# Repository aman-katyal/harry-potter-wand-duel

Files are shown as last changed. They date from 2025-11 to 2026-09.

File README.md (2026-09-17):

# Harry Potter Wand Duel - Embedded Edge-AI System

An interactive, dual-wand dueling system built on the Raspberry Pi RP2040 microcontroller. The wand tracks physical spell-casting gestures in real time using on-device machine learning (TinyML), transmits spell data wirelessly over 38 kHz modulated infrared, renders real-time combat status and animations on a 16x16 RGB LED matrix, and delivers tactile feedback via an onboard haptic motor driver.

Designed and developed for **ECE 362: Microprocessor Systems and Interfacing** at Purdue University.

---

## System Architecture

```
                      +-------------------------------------------------------+
                      |                 Raspberry Pi RP2040                   |
                      |                                                       |
                      |  +-------------------------------------------------+  |
                      |  | Core 0: Real-Time Engine & Peripherals          |  |
                      |  |                                                 |  |
                      |  |  * 74 Hz IMU Poller (BNO085 over I2C0)          |  |
                      |  |  * 3-Second 6-Axis Ring Buffer                  |  |
                      |  |  * WS2812 16x16 Matrix Controller (PIO + DMA)   |  |
                      |  |  * 38 kHz NEC IR Transmitter (PIO State Machine)|  |
                      |  |  * NEC Demodulating IR Receiver (PIO Interrupt) |  |
                      |  |  * DRV2605 Haptic Feedback (I2C0)               |  |
                      |  |  * Game State Machine, Health Bar & Shield Logic|  |
                      |  +-----------------------+-------------------------+  |
                      |                          |                             |
                      |                  Multicore Hardware                    |
                      |                    FIFO + Mutex                        |
                      |                          |                             |
                      |  +-----------------------v-------------------------+  |
                      |  | Core 1: TinyML Inference Engine                 |  |
                      |  |                                                 |  |
                      |  |  * Edge Impulse TFLite Micro Runtime            |  |
                      |  |  * 1650 ms Sliding Window Feature Extractor     |  |
                      |  |  * CMSIS-DSP Accelerated Neural Classifier      |  |
                      |  |  * K-Means Anomaly Detection Engine             |  |
                      |  +-------------------------------------------------+  |
                      +-------------------------------------------------------+
```

---

## Hardware Specifications

| Component | Part / IC | Interface | Description |
|---|---|---|---|
| **Microcontroller** | SparkFun Pro Micro RP2040 | Dual ARM Cortex-M0+ @ 133 MHz | Primary compute module with 264 KB SRAM and 2 MB Flash. |
| **Inertial Measurement** | Adafruit BNO085 | I2C0 (Fast Mode, 400 kHz) | 9-DOF IMU with onboard ARM Cortex-M0+ running Hillcrest SH-2 sensor fusion (Linear Accel + Rotation Vector). |
| **Haptics** | TI DRV2605L | I2C0 (Shared bus) | ERM/LRA haptic driver providing distinct wave sensations for spell casts, hits, and shield deployment. |
| **Display Matrix** | 16x16 WS2812B (256 LEDs) | PIO0 (Custom State Machine) | High-speed serialized 800 kHz pixel protocol driven directly by RP2040 PIO with no CPU bit-banging. |
| **IR Transmitter** | 940 nm High-Output IR LED | PIO1 (38 kHz Carrier Generator) | Hardware-timed NEC protocol encoding with 38 kHz carrier frequency modulation. |
| **IR Receiver** | TSOP38238 (38 kHz Demodulator) | PIO / Edge-triggered ISR | Demodulates incoming player commands and validates opponent player IDs. |
| **Shield Trigger** | Tactile Switch | GPIO 21 (Active High) | Hardware input to raise the defensive barrier and trigger hit immunity. |
| **Custom PCB** | 2-Layer KiCad Design | Multi-rail Power (5V / 3.3V) | Custom wand PCB integrating MCU, sensor breakouts, power regulation, and FET driver circuits. |

---

## Key Technical Challenges & Engineering Solutions

### 1. Dual-Core Real-Time Decoupling
Running TinyML neural network inference on continuous 6-axis sensor streams requires 60–90 ms of sustained computation per window. If executed synchronously on a single core:
- Sensor polling intervals would jitter, corrupting frequency-domain feature extraction.
- Incoming 38 kHz IR pulses would be dropped, causing missed hits during combat.
- LED matrix refresh routines would stall, resulting in visible visual stutter.

**Solution:** The system splits tasks across both RP2040 cores:
- **Core 0** handles strictly deterministic real-time tasks: reading the BNO085 at exactly 74 Hz, pushing samples to a circular buffer, rendering animations, managing IR transceiver state machines, and evaluating the duel state machine.
- **Core 1** operates as a co-processor dedicated solely to TinyML execution. When Core 0 detects an active gesture, it copies a 1650 ms sliding window (732 float features) into an exchange buffer and signals Core 1. Core 1 runs inference and returns a packed 32-bit result (`spell_id`, `confidence`, `anomaly_score`) via the RP2040 hardware FIFO.

### 2. False-Positive Filtering ("Leaky Bucket" Accumulator)
Natural wand handling and rapid arm movements can produce transient sensor spikes that momentarily fool an ML classifier.
- Instead of firing immediately on a single inference hit, the firmware uses an integrating leaky-bucket filter (`SPELL_TRIGGER_TARGET = 7`, `SPELL_DECAY_RATE = 2`).
- A spell is only cast when consecutive inferences consistently recognize the same gesture above the confidence threshold (`>= 0.90`).
- Individual spells use dynamic anomaly ceilings (e.g., `2.3` for Aguamenti vs. `2.6` for Stupefy) to cleanly reject out-of-distribution movements.

### 3. Hardware Peripheral Offloading via PIO
- **WS2812B Protocol:** Rather than tying up the CPU with tight assembly loops for the strict 800 kHz NZR timing, a custom PIO program streams pixel color buffers directly to the matrix.
- **38 kHz IR Modulation:** The 38 kHz carrier square wave and NEC pulse-distance bit-timing are generated in hardware using a PIO state machine, ensuring precise modulation independent of CPU load.

---

## Combat & Game Mechanics

- **Spells:**
  - **Aguamenti (Water Spell):** Forward-sweeping motion -> triggers blue matrix firework animation, distinct haptic vibration, and broadcasts NEC command `10` over IR. Deals 2 damage.
  - **Stupefy (Stun Spell):** Sharp diagonal slash -> triggers red matrix firework animation, heavy haptic jolt, and broadcasts NEC command `20` over IR. Deals 2 damage.
- **Protego (Shield):** Pressing the shield button deploys an animated protective blue barrier on the matrix for 1.5 seconds. During this window, any incoming IR hits are flushed from the queue and ignored (temporary immunity). A 10-second cooldown timer is enforced before the shield can be redeployed.
- **Health System:** A perimeter health bar tracks player health (initialized to 10 HP). When health drops to 0, an animated defeat screen is displayed and casting is locked out until respawn.
- **Multiplayer Duel Configuration:**
  - In [`firmware/src/sys_config.h`](firmware/src/sys_config.h), set `PLAYER_ID` to `1` or `2` to assign wand identity.
  - Set `ALLOW_SELF_HIT` to `1` for single-wand solo testing, or `0` for two-player competitive duels (to prevent bouncing off walls and self-inflicting damage).

---

## Hardware Pinout Map

| RP2040 GPIO | Function | Peripheral |
|---|---|---|
| **GPIO 4** | I2C0 SDA | BNO085 IMU & DRV2605 Haptic Driver |
| **GPIO 5** | I2C0 SCL | BNO085 IMU & DRV2605 Haptic Driver |
| **GPIO 6** | Input / PIO | TSOP38238 38 kHz IR Receiver |
| **GPIO 16** | Output / PIO | IR LED Driver (38 kHz modulated output) |
| **GPIO 20** | Output / PIO | WS2812B 16x16 LED Matrix Data Line |
| **GPIO 21** | Input (Pull-Down) | Shield Tactile Switch |

---

## Repository Structure

```
.
├── firmware/                   # Primary dual-core wand firmware (PlatformIO project)
│   ├── src/                    # Application source files
│   │   ├── main.c              # Core 0 loop, hardware init, duel logic, IR/LED handling
│   │   ├── sys_config.h        # Pin assignments, tuning thresholds, player identity
│   │   ├── ei_bridge.cpp       # Edge Impulse C++ wrapper for Core 1 inference
│   │   └── ei_bridge.h
│   ├── lib/                    # Device drivers and neural network model
│   │   ├── Adafruit_BNO08x/    # Hillcrest SH-2 IMU driver
│   │   ├── haptics/            # DRV2605 haptic motor driver
│   │   ├── ir_receiver/        # NEC IR decoder implementation
│   │   ├── ir_transmitter/     # NEC IR encoder & emitter
│   │   ├── led_matrix/         # Matrix animations (fireworks, shield, healthbar)
│   │   └── edge-impulse-model/ # Exported TinyML model with CMSIS-DSP kernels
│   ├── pio/                    # PIO assembly files (WS2812 timing, IR carrier)
│   └── platformio.ini          # Build configuration (Pico-SDK, multicore, CMSIS flags)
│
├── hardware/                   # KiCad electrical design & PCB layout
│   ├── ece362project.kicad_sch # Top-level schematic
│   ├── ece362project.kicad_pcb # 2-layer routed PCB layout
│   ├── *.kicad_sch             # Hierarchical schematic sheets (power, IMU, haptics, etc.)
│   ├── components/             # Custom footprints and symbol libraries
│   └── manufacturing/          # Fabrication gerber files, drill files, and BOM
│
├── prototypes/                 # Isolated subsystem test benches used during bring-up
│   ├── haptics/                # DRV2605 waveform testing
│   ├── imu/                    # BNO08x orientation & acceleration logging
│   ├── ir_receiver/            # IR receiver timing & decoding tests
│   ├── ir_transmitter/         # IR transmitter carrier & burst verification
│   └── led_matrix/             # LED animation test bench
│
└── archive/                    # Developmental prototype snapshots
```

---

## Building & Flashing

### Prerequisites
- [PlatformIO Core](https://platformio.org/) (CLI) or PlatformIO IDE extension for VS Code.
- Raspberry Pi Pico toolchain with Pico-SDK support.
- A SWD debugger (e.g. Raspberry Pi Picoprobe) or standard USB BOOTSEL drag-and-drop.

### Build
Navigate to the firmware directory and compile:
```bash
cd firmware
pio run
```

### Flash via Picoprobe
```bash
pio run -t upload
```

### Serial Monitor
To view real-time debug telemetry (gesture scores, anomaly ratings, hit events):
```bash
pio device monitor -b 115200
```

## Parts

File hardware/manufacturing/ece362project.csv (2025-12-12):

Reference | Value | Datasheet | Footprint | Qty | DNP
C1,C5,C6,C7 | 10uF | ~ | Capacitor_SMD:C_0603_1608Metric | 4
C2 | 22uF | ~ | Capacitor_SMD:C_0603_1608Metric | 1
C8,C9,C10,C11 | 1uF | ~ | Capacitor_SMD:C_0603_1608Metric | 4
D1,D2,D3 | LED | ~ | LED_SMD:LED_0603_1608Metric | 3
J1,J12,J16,J18 | Conn_01x28_Socket | ~ | Connector_PinSocket_2.54mm:PinSocket_1x28_P2.54mm_Vertical | 4
J2 | Conn_01x05_Socket | ~ | Connector_PinHeader_2.54mm:PinHeader_1x05_P2.54mm_Vertical | 1
J3,J4,J7,J8 | 1751248 | 1751248 | 2x1term:CONN_1751248_PXC | 4
J5,J14,J17 | Conn_01x03_Socket | ~ | Connector_PinSocket_2.54mm:PinSocket_1x03_P2.54mm_Vertical | 3
J6,J10,J11 | 691137710003 |  | 3x1term:691137710003 | 3
J9 | 284414-6 | https://www.te.com/commerce/DocumentDelivery/DDEController?Action=srchrtrv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 | 6x1term:CONN6_284414-6_TEC | 1
J13,J19 | Conn_01x04_Socket | ~ | Connector_PinHeader_2.54mm:PinHeader_1x04_P2.54mm_Vertical | 2
J15 | USB_C_Receptacle_PowerOnly_6P | https://www.usb.org/sites/default/files/documents/usb_type-c.zip | Connector_USB:USB_C_Receptacle_GCT_USB4125-xx-x-0190_6P_TopMnt_Horizontal | 1
JP1,JP2,JP3,JP4,JP5,JP6,JP7,JP8,JP9 | Jumper_2_Open | ~ | TestPoint:TestPoint_2Pads_Pitch2.54mm_Drill0.8mm | 9
Q1 | AO3406 | https://mm.digikey.com/Volume0/opasdata/d220001/medias/docus/1063/AO3406.pdf | Package_TO_SOT_SMD:SOT-23-3 | 1
R1,R8 | 5.1K | ~ | Resistor_SMD:R_0603_1608Metric | 2
R2,R3,R6,R7,R11,R12 | 10k | ~ | Resistor_SMD:R_0603_1608Metric | 6
R4,R5 | 22 | ~ | Resistor_SMD:R_0603_1608Metric | 2
R9,R10 | 220 | ~ | Resistor_SMD:R_0603_1608Metric | 2
TP1,TP2,TP3,TP4,TP5,TP6,TP7,TP8,TP9,TP10 | TestPoint | ~ | TestPoint:TestPoint_Pad_3.0x3.0mm | 10
U1,U3 | DRV2605LDGS | http://www.ti.com/lit/ds/symlink/drv2605l.pdf | Package_SO:VSSOP-10_3x3mm_P0.5mm | 2
U2 | 4754 |  | bno085:MODULE_4754 | 1
U4 | AZ1117IH-3.3TRG1 | https://www.diodes.com/assets/Datasheets/AZ1117I.pdf | ldo:SOT230P700X185-4N | 1

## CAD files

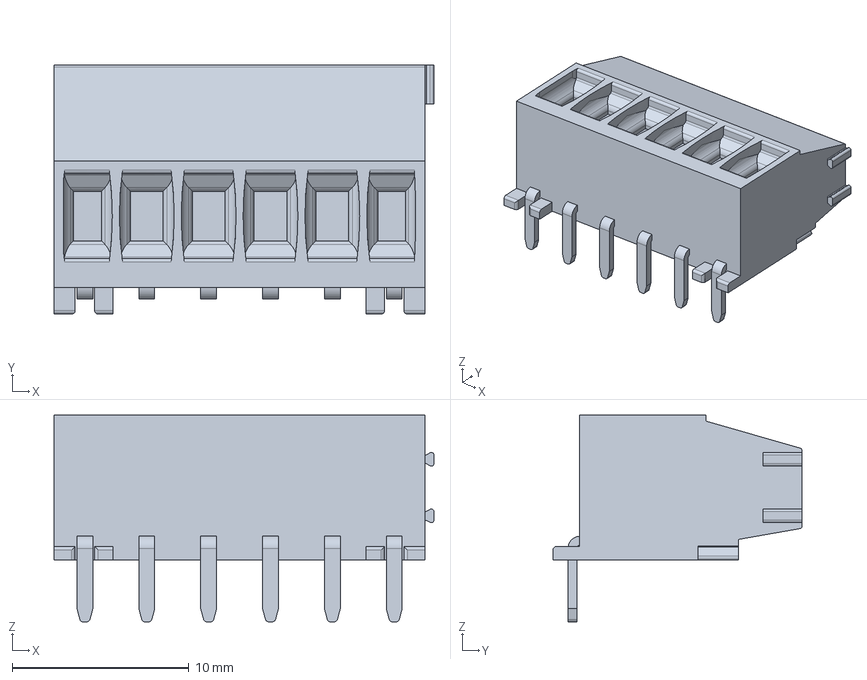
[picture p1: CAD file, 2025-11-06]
hardware/components/(imuterm)284414_6/c-284414-6-c-3d.stp
21.5 x 14.1 x 11.7 mm

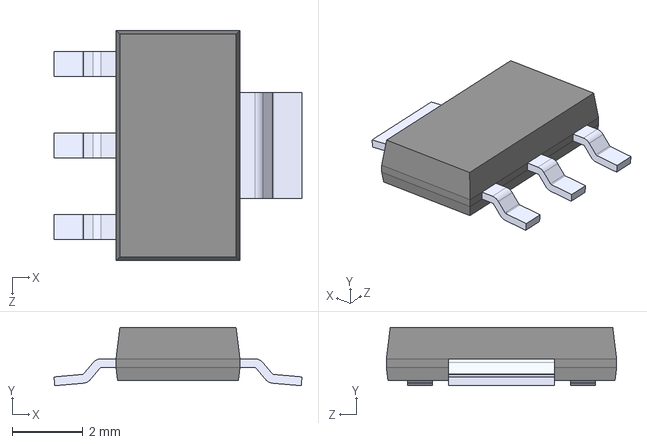
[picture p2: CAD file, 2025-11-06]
hardware/components/AZ1117IH_3_3TRG1/AZ1117IH-3.3TRG1.step
7.00 x 1.65 x 6.50 mm

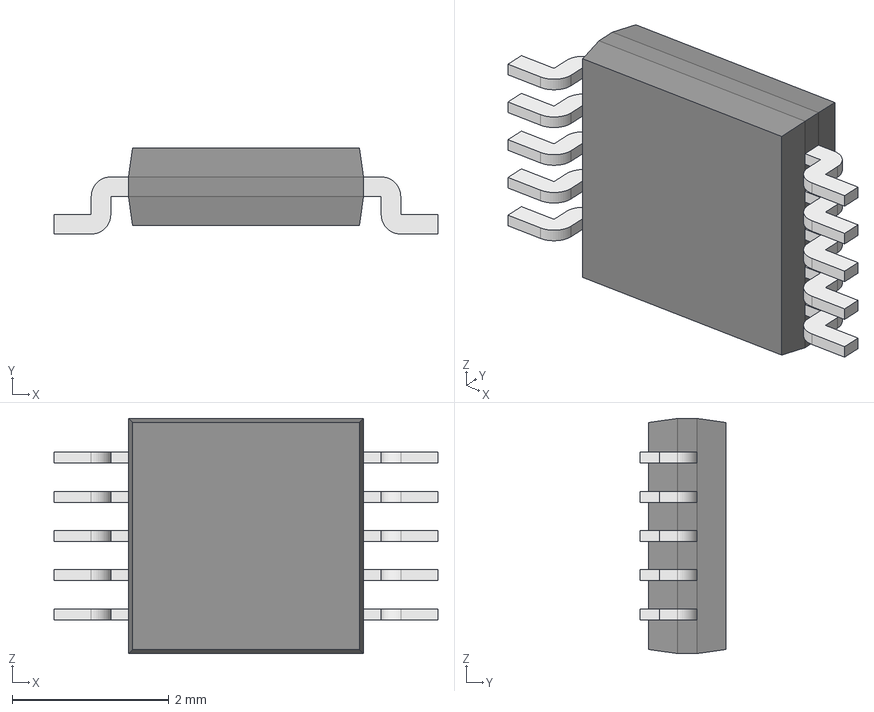
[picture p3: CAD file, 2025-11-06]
hardware/components/DRV2605LDGSR/DRV2605LDGSR.step
4.90 x 1.10 x 3.00 mm
Body001 (Mirror #1) x 5
XY-plane x 12
X-axis x 12

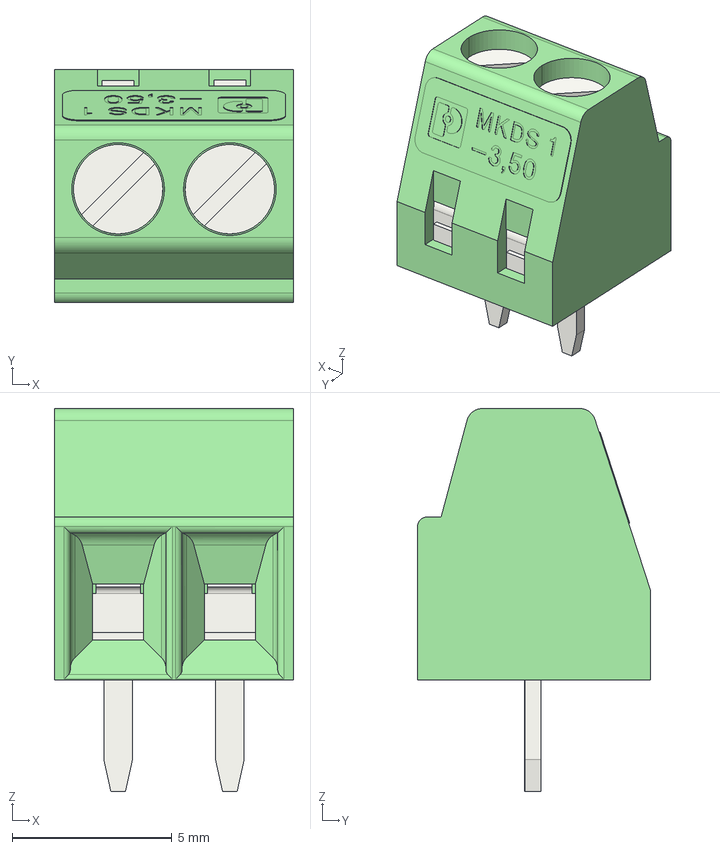
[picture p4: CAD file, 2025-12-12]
hardware/components/(2x1_term)1751248/1751248.stp
7.50 x 7.30 x 12.0 mm

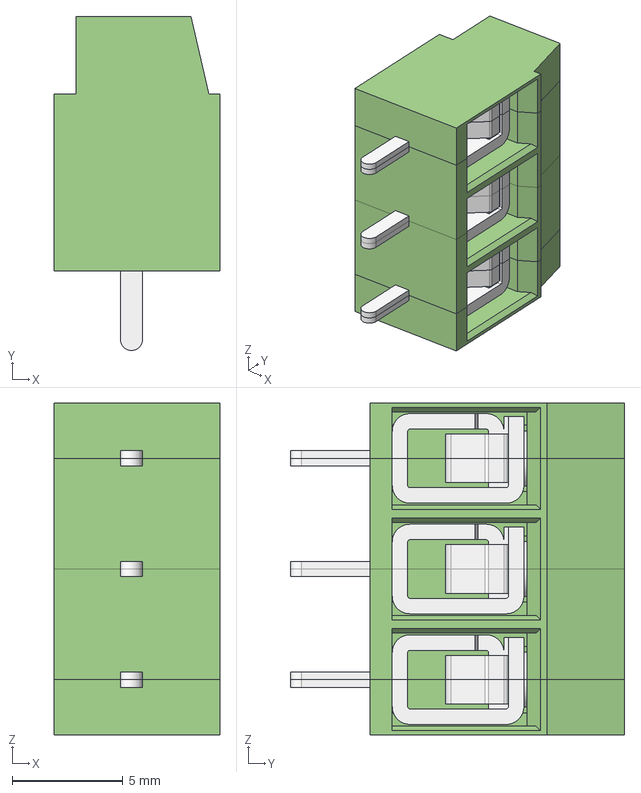
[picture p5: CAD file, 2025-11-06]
hardware/components/(691137710003)screw_terminal 3x1/Download_STP_691137710003_rev1.stp
7.50 x 15.1 x 15.0 mm
MRT12P5_SX
MRT12P5_CNT x 2
MRT12P5_DX

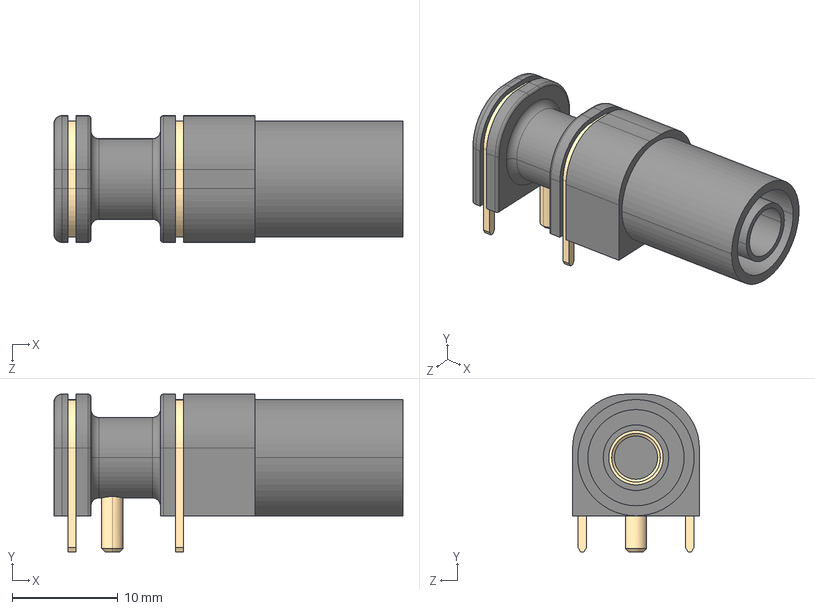
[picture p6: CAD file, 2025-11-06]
hardware/components/banana plug)73099_0/73099-0.step
33.0 x 14.9 x 12.0 mm

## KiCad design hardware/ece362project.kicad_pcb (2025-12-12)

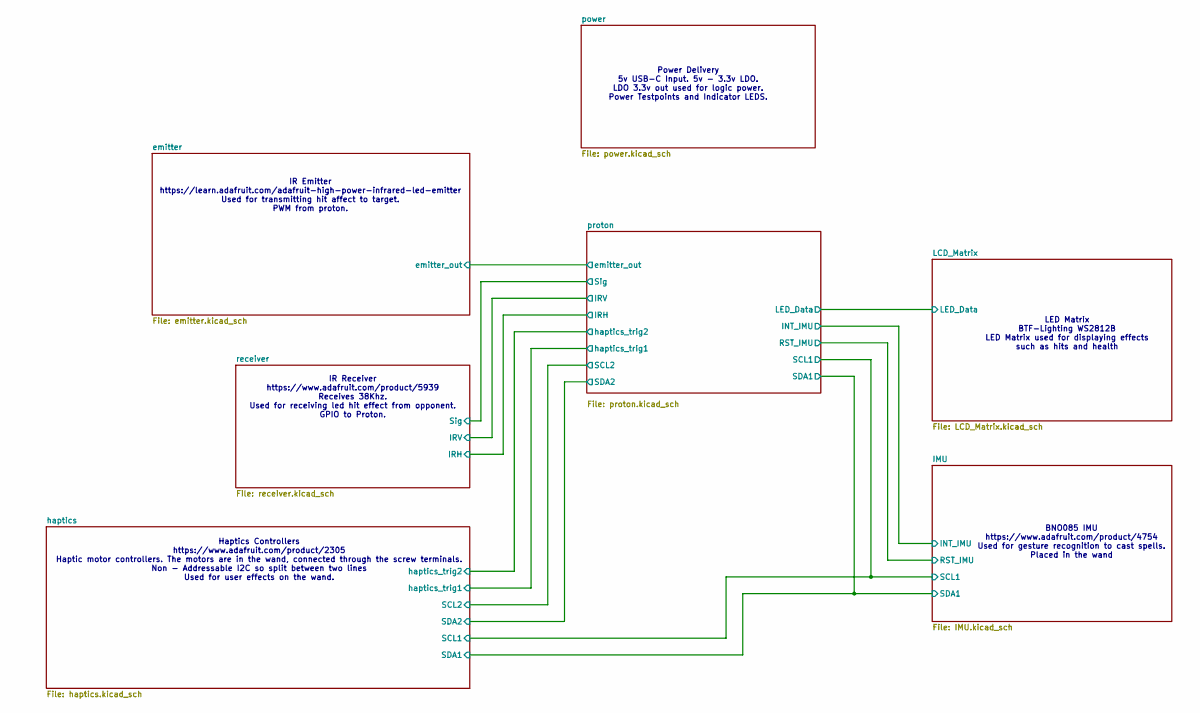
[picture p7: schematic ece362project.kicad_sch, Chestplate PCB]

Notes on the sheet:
IR Emitter https://learn.adafruit.com/adafruit-high-power-infrared-led-emitter Used for transmitting hit affect to target. PWM from proton.
LED Matrix BTF-Lighting WS2812B LED Matrix used for displaying effects such as hits and health
BNO085 IMU https://www.adafruit.com/product/4754 Used for gesture recognition to cast spells. Placed in the wand
Power Delivery 5v USB-C Input. 5v - 3.3v LDO. LDO 3.3v out used for logic power. Power Testpoints and Indicator LEDS.
Haptics Controllers https://www.adafruit.com/product/2305 Haptic motor controllers. The motors are in the wand, connected through the screw terminals. Non - Addressable I2C so split between two lines Used for user effects on the wand.
IR Receiver https://www.adafruit.com/product/5939 Receives 38Khz. Used for receiving led hit effect from opponent. GPIO to Proton.

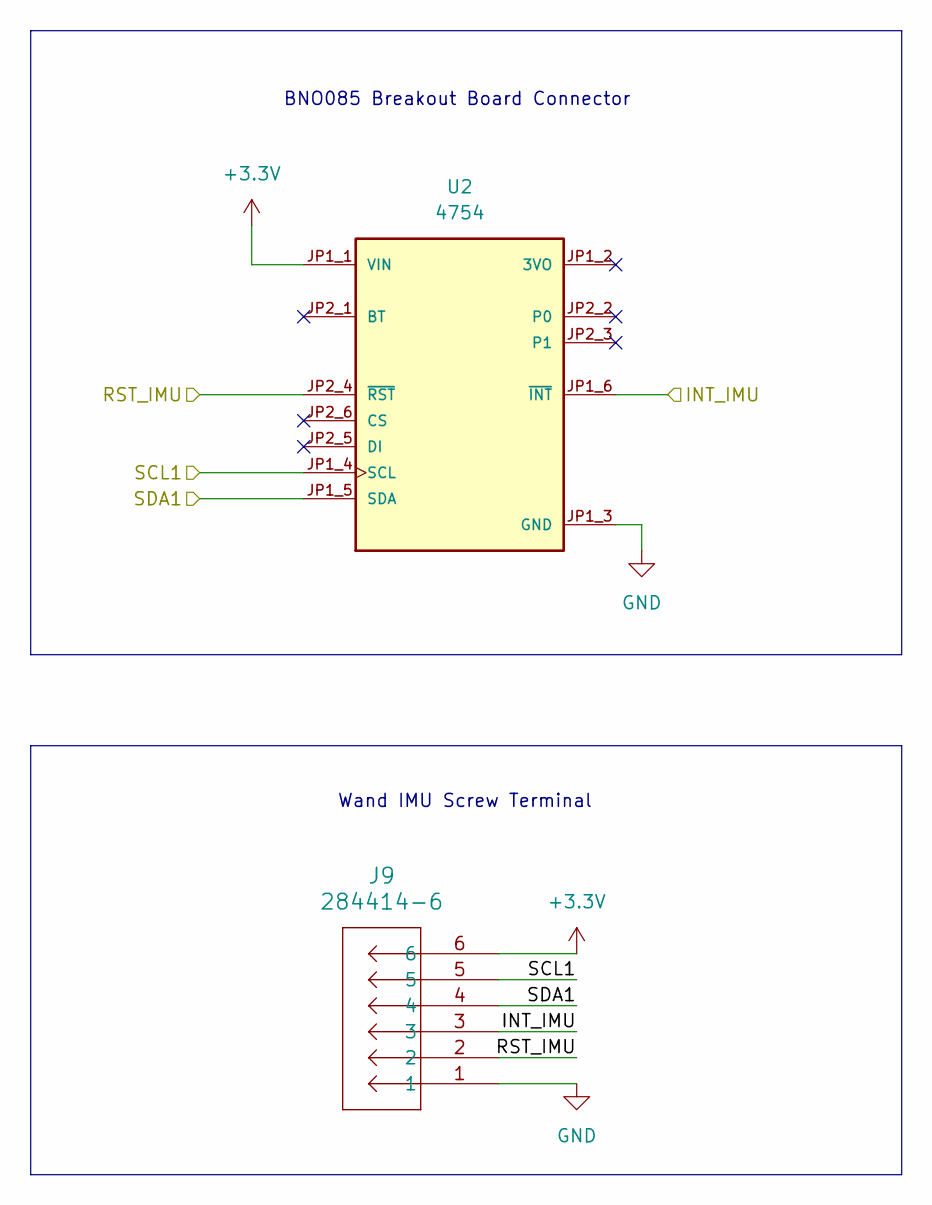
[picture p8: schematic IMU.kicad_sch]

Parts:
J9: 284414-6; CONN6_284414-6_TEC
U2: 4754; MODULE_4754; PARTREV 2021-03-16

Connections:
+3.3V: J9.6, U2.JP1_1 (VIN); also elsewhere on the board
/IMU/INT_IMU: J9.3, U2.JP1_6 (~INT); also elsewhere on the board
/IMU/RST_IMU: J9.2, U2.JP2_4 (~RST); also elsewhere on the board
/IMU/SCL1: J9.5, U2.JP1_4 (SCL); also elsewhere on the board
/IMU/SDA1: J9.4, U2.JP1_5 (SDA); also elsewhere on the board
GND: J9.1, U2.JP1_3 (GND); also elsewhere on the board

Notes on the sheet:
BNO085 Breakout Board Connector
Wand IMU Screw Terminal

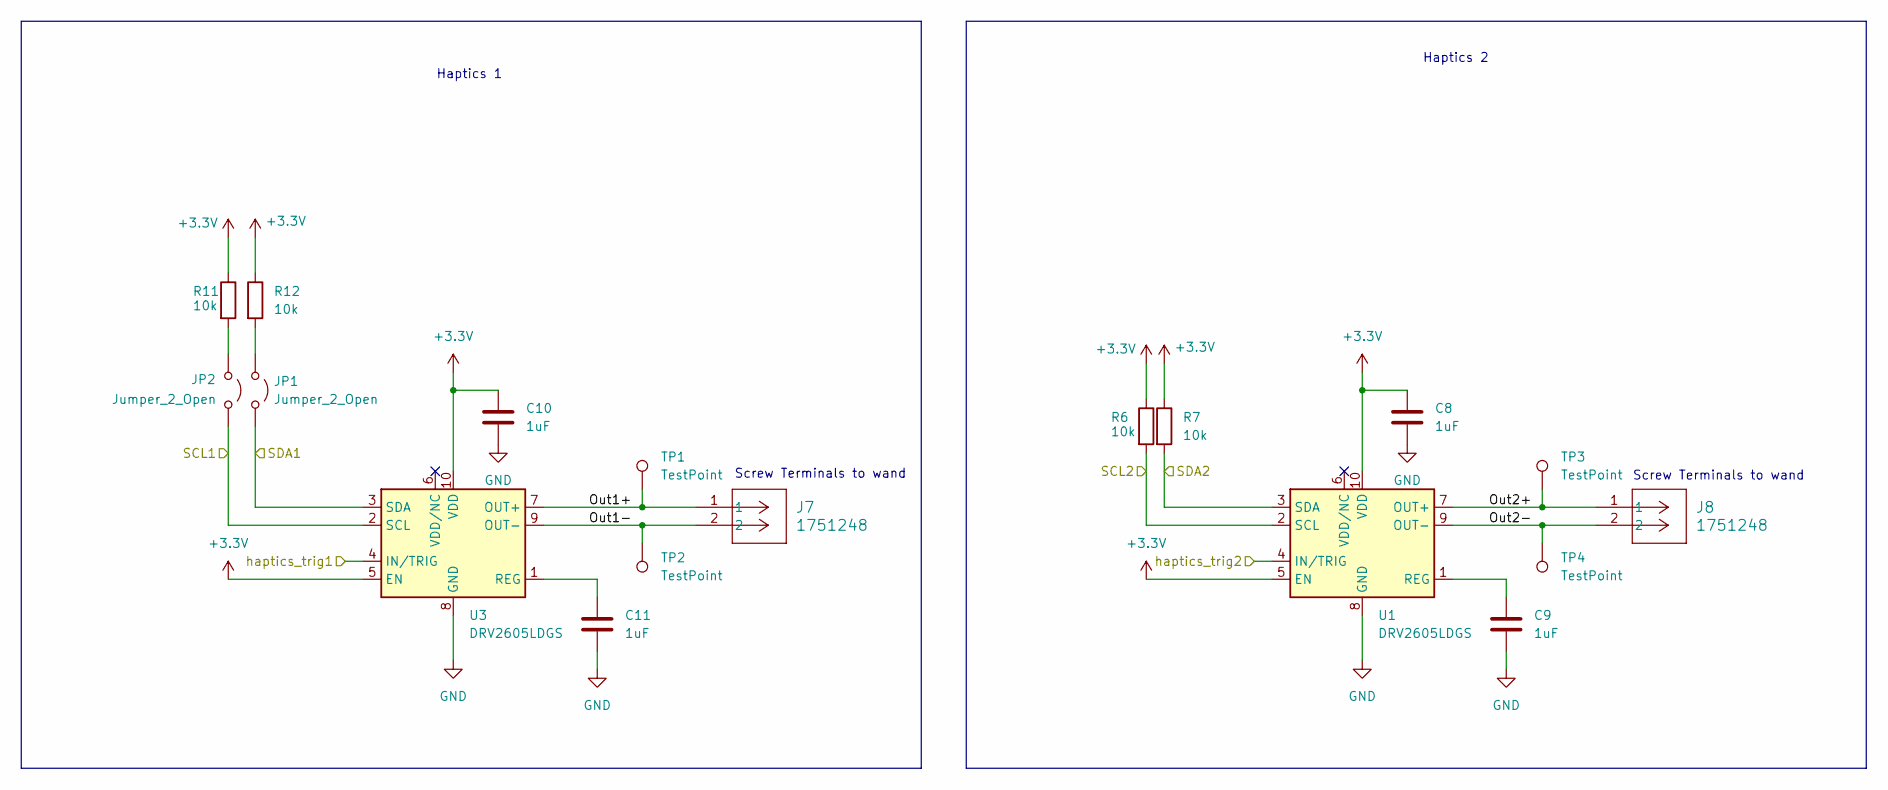
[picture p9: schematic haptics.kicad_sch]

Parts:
C8, C9, C10, C11: 1uF; C_0603_1608Metric
J7, J8: 1751248; CONN_1751248_PXC
JP1, JP2: Jumper_2_Open; TestPoint_2Pads_Pitch2.54mm_Drill0.8mm
R6, R7, R11, R12: 10k; R_0603_1608Metric
TP1, TP2, TP3, TP4: TestPoint; TestPoint_Pad_3.0x3.0mm
U1, U3: DRV2605LDGS; VSSOP-10_3x3mm_P0.5mm

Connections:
+3.3V: C8.1, C10.1, R6.1, R7.1, R11.1, R12.1, U1.5 (EN), U1.10 (VDD), U3.5 (EN), U3.10 (VDD); also elsewhere on the board
/IMU/SCL1: JP2.2 (B), U3.2 (SCL); also elsewhere on the board
/IMU/SDA1: JP1.2 (B), U3.3 (SDA); also elsewhere on the board
/haptics/Out1+: J7.1, TP1.1, U3.7 (OUT+)
/haptics/Out1-: J7.2, TP2.1, U3.9 (OUT-)
/haptics/Out2+: J8.1, TP3.1, U1.7 (OUT+)
/haptics/Out2-: J8.2, TP4.1, U1.9 (OUT-)
/haptics/SCL2: R6.2, U1.2 (SCL); also elsewhere on the board
/haptics/SDA2: R7.2, U1.3 (SDA); also elsewhere on the board
/haptics/haptics_trig1: U3.4 (IN/TRIG); also elsewhere on the board
/haptics/haptics_trig2: U1.4 (IN/TRIG); also elsewhere on the board
GND: C8.2, C9.2, C10.2, C11.2, U1.8 (GND), U3.8 (GND); also elsewhere on the board
unnamed: JP1.1 (A), R12.2
unnamed: JP2.1 (A), R11.2
unnamed: C9.1, U1.1 (REG)
unnamed: C11.1, U3.1 (REG)

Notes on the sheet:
Haptics 1
Screw Terminals to wand
Haptics 2

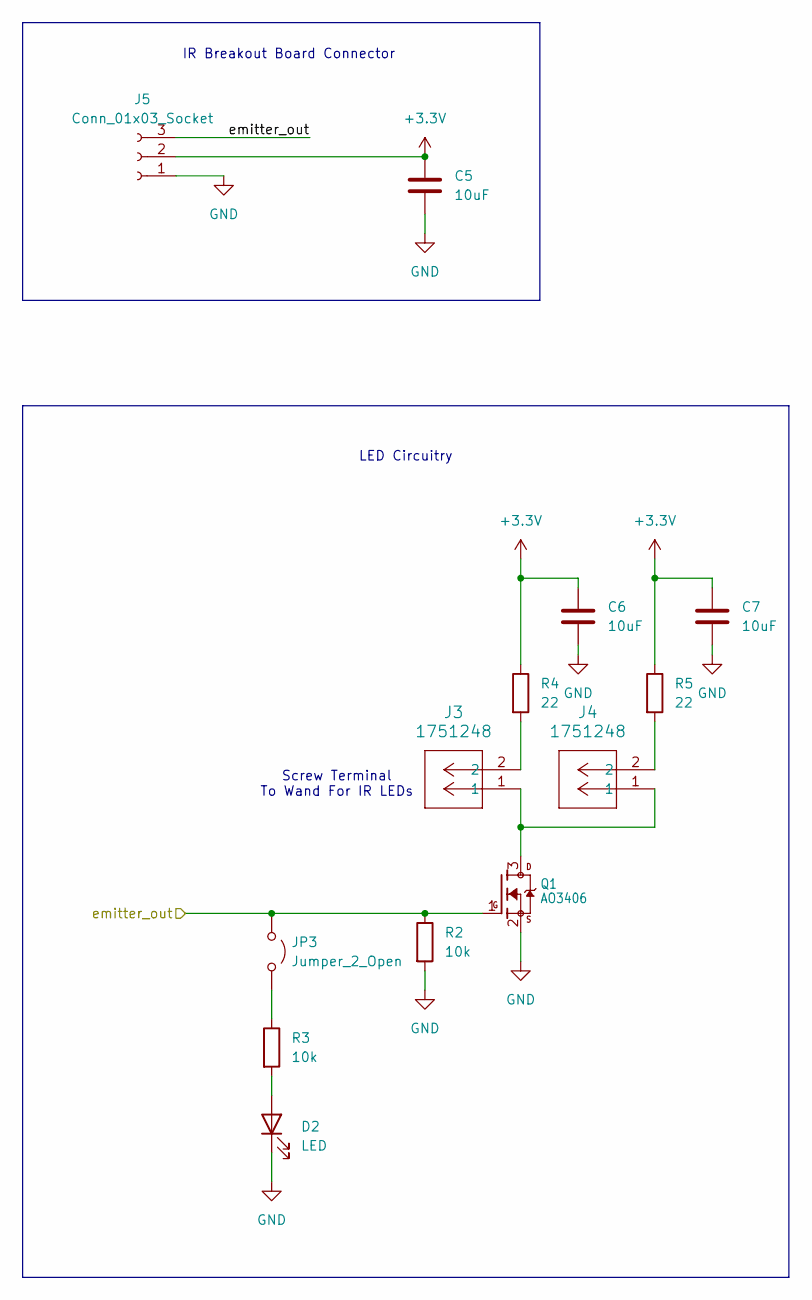
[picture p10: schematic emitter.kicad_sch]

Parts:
C5, C6, C7: 10uF; C_0603_1608Metric
D2: LED; LED_0603_1608Metric
J3, J4: 1751248; CONN_1751248_PXC
J5: Conn_01x03_Socket; PinSocket_1x03_P2.54mm_Vertical
JP3: Jumper_2_Open; TestPoint_2Pads_Pitch2.54mm_Drill0.8mm
Q1: AO3406; SOT-23-3
R2, R3: 10k; R_0603_1608Metric
R4, R5: 22; R_0603_1608Metric

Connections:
+3.3V: C5.1, C6.1, C7.1, J5.2, R4.1, R5.1; also elsewhere on the board
/emitter/emitter_out: J5.3, JP3.1 (A), Q1.1 (G), R2.1; also elsewhere on the board
GND: C5.2, C6.2, C7.2, D2.1 (K), J5.1, Q1.2 (S), R2.2; also elsewhere on the board
unnamed: D2.2 (A), R3.2
unnamed: J3.2, R4.2
unnamed: J4.2, R5.2
unnamed: JP3.2 (B), R3.1
unnamed: J3.1, J4.1, Q1.3 (D)

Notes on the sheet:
Screw Terminal To Wand For IR LEDs
IR Breakout Board Connector
LED Circuitry

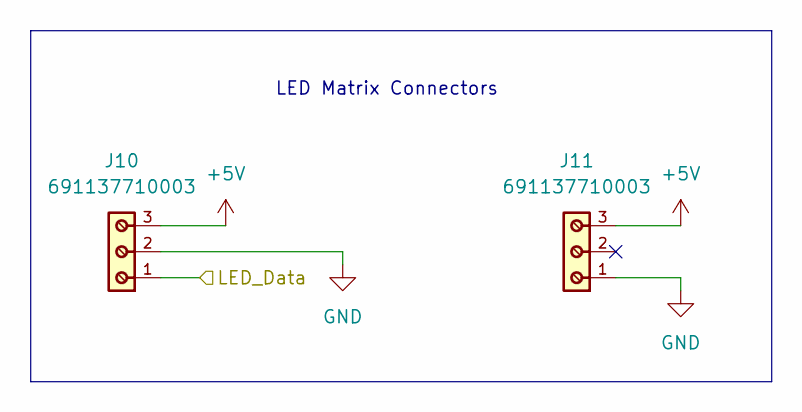
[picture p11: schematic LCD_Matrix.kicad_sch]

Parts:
J10, J11: 691137710003

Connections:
+5V: J10.3, J11.3; also elsewhere on the board
/LCD_Matrix/LED_Data: J10.1; also elsewhere on the board
GND: J10.2, J11.1; also elsewhere on the board

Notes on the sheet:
LED Matrix Connectors

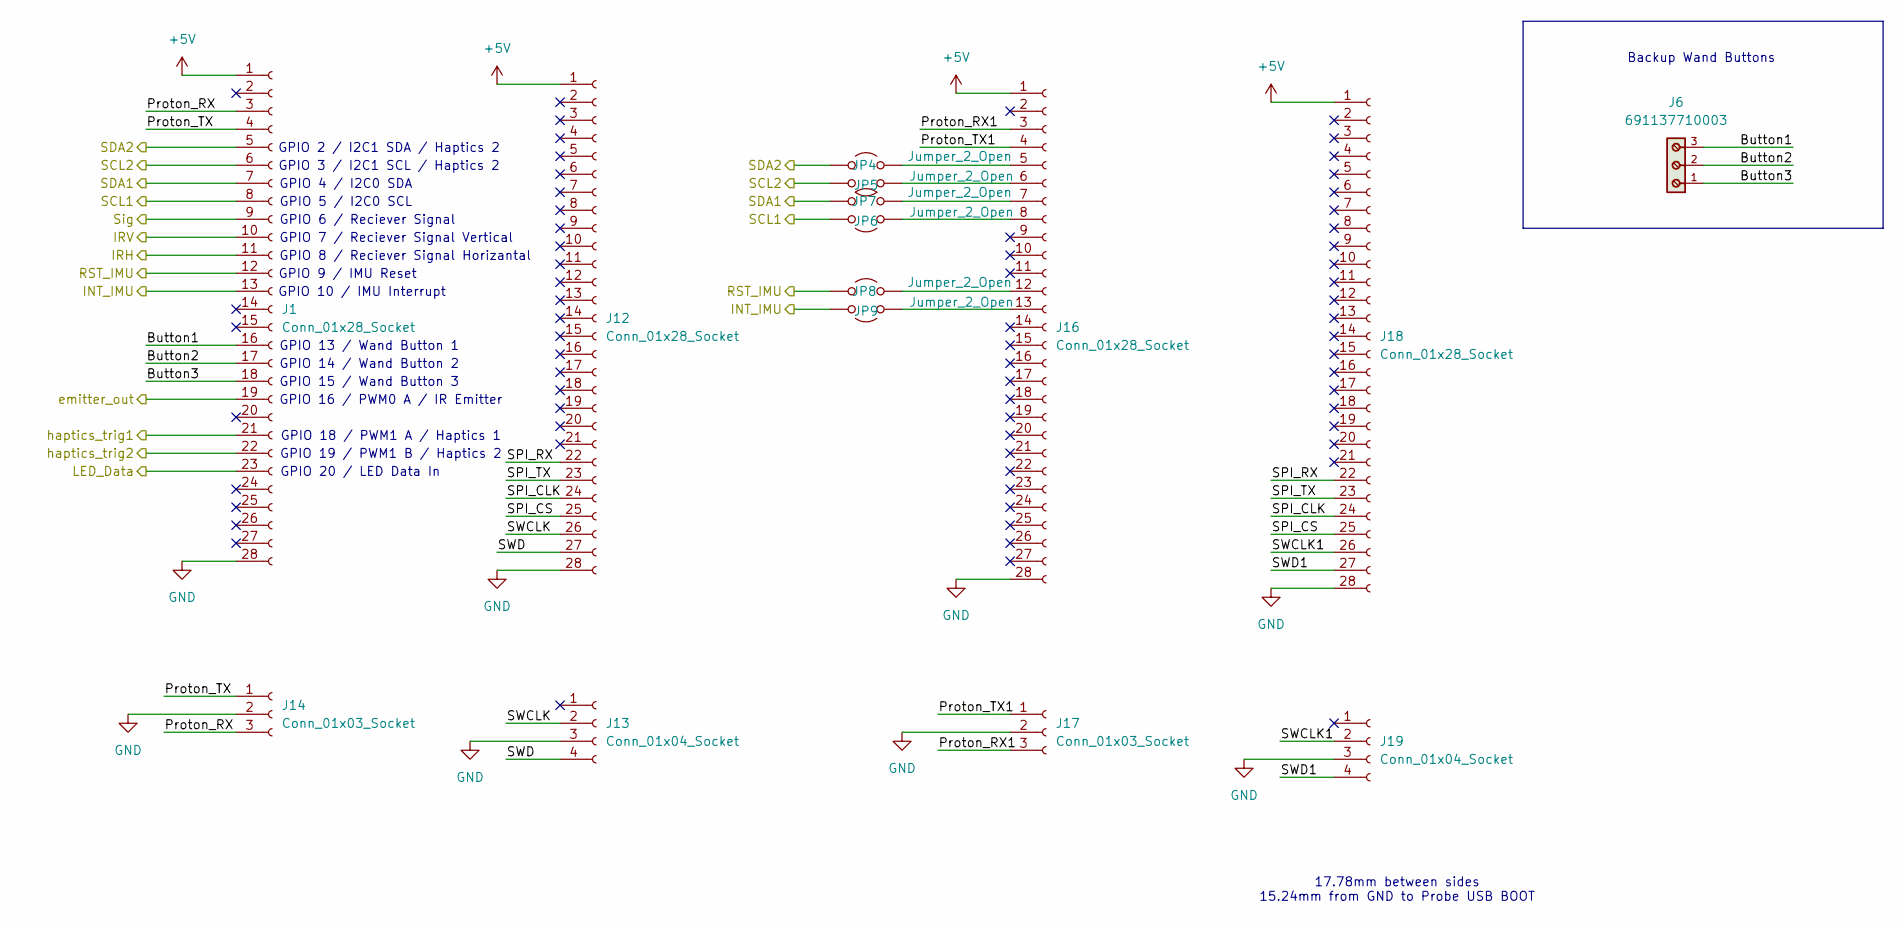
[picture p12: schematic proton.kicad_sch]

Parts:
J1, J12, J16, J18: Conn_01x28_Socket; PinSocket_1x28_P2.54mm_Vertical
J6: 691137710003
J13, J19: Conn_01x04_Socket; PinHeader_1x04_P2.54mm_Vertical
J14, J17: Conn_01x03_Socket; PinSocket_1x03_P2.54mm_Vertical
JP4, JP5, JP6, JP7, JP8, JP9: Jumper_2_Open; TestPoint_2Pads_Pitch2.54mm_Drill0.8mm

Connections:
+5V: J1.1, J12.1, J16.1, J18.1; also elsewhere on the board
/IMU/INT_IMU: J1.13, JP9.2 (B); also elsewhere on the board
/IMU/RST_IMU: J1.12, JP8.1 (A); also elsewhere on the board
/IMU/SCL1: J1.8, JP6.2 (B); also elsewhere on the board
/IMU/SDA1: J1.7, JP7.1 (A); also elsewhere on the board
/LCD_Matrix/LED_Data: J1.23; also elsewhere on the board
/emitter/emitter_out: J1.19; also elsewhere on the board
/haptics/SCL2: J1.6, JP5.2 (B); also elsewhere on the board
/haptics/SDA2: J1.5, JP4.1 (A); also elsewhere on the board
/haptics/haptics_trig1: J1.21; also elsewhere on the board
/haptics/haptics_trig2: J1.22; also elsewhere on the board
/proton/Button1: J1.16, J6.3
/proton/Button2: J1.17, J6.2
/proton/Button3: J1.18, J6.1
/proton/IRH: J1.11; also elsewhere on the board
/proton/IRV: J1.10; also elsewhere on the board
/proton/Proton_RX: J1.3, J14.3
/proton/Proton_RX1: J16.3, J17.3
/proton/Proton_TX: J1.4, J14.1
/proton/Proton_TX1: J16.4, J17.1
/proton/SPI_CLK: J12.24, J18.24
/proton/SPI_CS: J12.25, J18.25
/proton/SPI_RX: J12.22, J18.22
/proton/SPI_TX: J12.23, J18.23
/proton/SWCLK: J12.26, J13.2
/proton/SWCLK1: J18.26, J19.2
/proton/SWD: J12.27, J13.4
/proton/SWD1: J18.27, J19.4
/proton/Sig: J1.9; also elsewhere on the board
GND: J1.28, J12.28, J13.3, J14.2, J16.28, J17.2, J18.28, J19.3; also elsewhere on the board
unnamed: J16.5, JP4.2 (B)
unnamed: J16.6, JP5.1 (A)
unnamed: J16.7, JP7.2 (B)
unnamed: J16.8, JP6.1 (A)
unnamed: J16.12, JP8.2 (B)
unnamed: J16.13, JP9.1 (A)

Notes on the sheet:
GPIO 7 / Reciever Signal Vertical
GPIO 15 / Wand Button 3
Backup Wand Buttons
GPIO 16 / PWM0 A / IR Emitter
GPIO 6 / Reciever Signal
GPIO 2 / I2C1 SDA / Haptics 2
GPIO 8 / Reciever Signal Horizantal
GPIO 5 / I2C0 SCL
GPIO 18 / PWM1 A / Haptics 1
GPIO 20 / LED Data In
GPIO 14 / Wand Button 2
GPIO 13 / Wand Button 1
GPIO 4 / I2C0 SDA
GPIO 9 / IMU Reset
GPIO 19 / PWM1 B / Haptics 2
17.78mm between sides 15.24mm from GND to Probe USB BOOT
GPIO 3 / I2C1 SCL / Haptics 2
GPIO 10 / IMU Interrupt

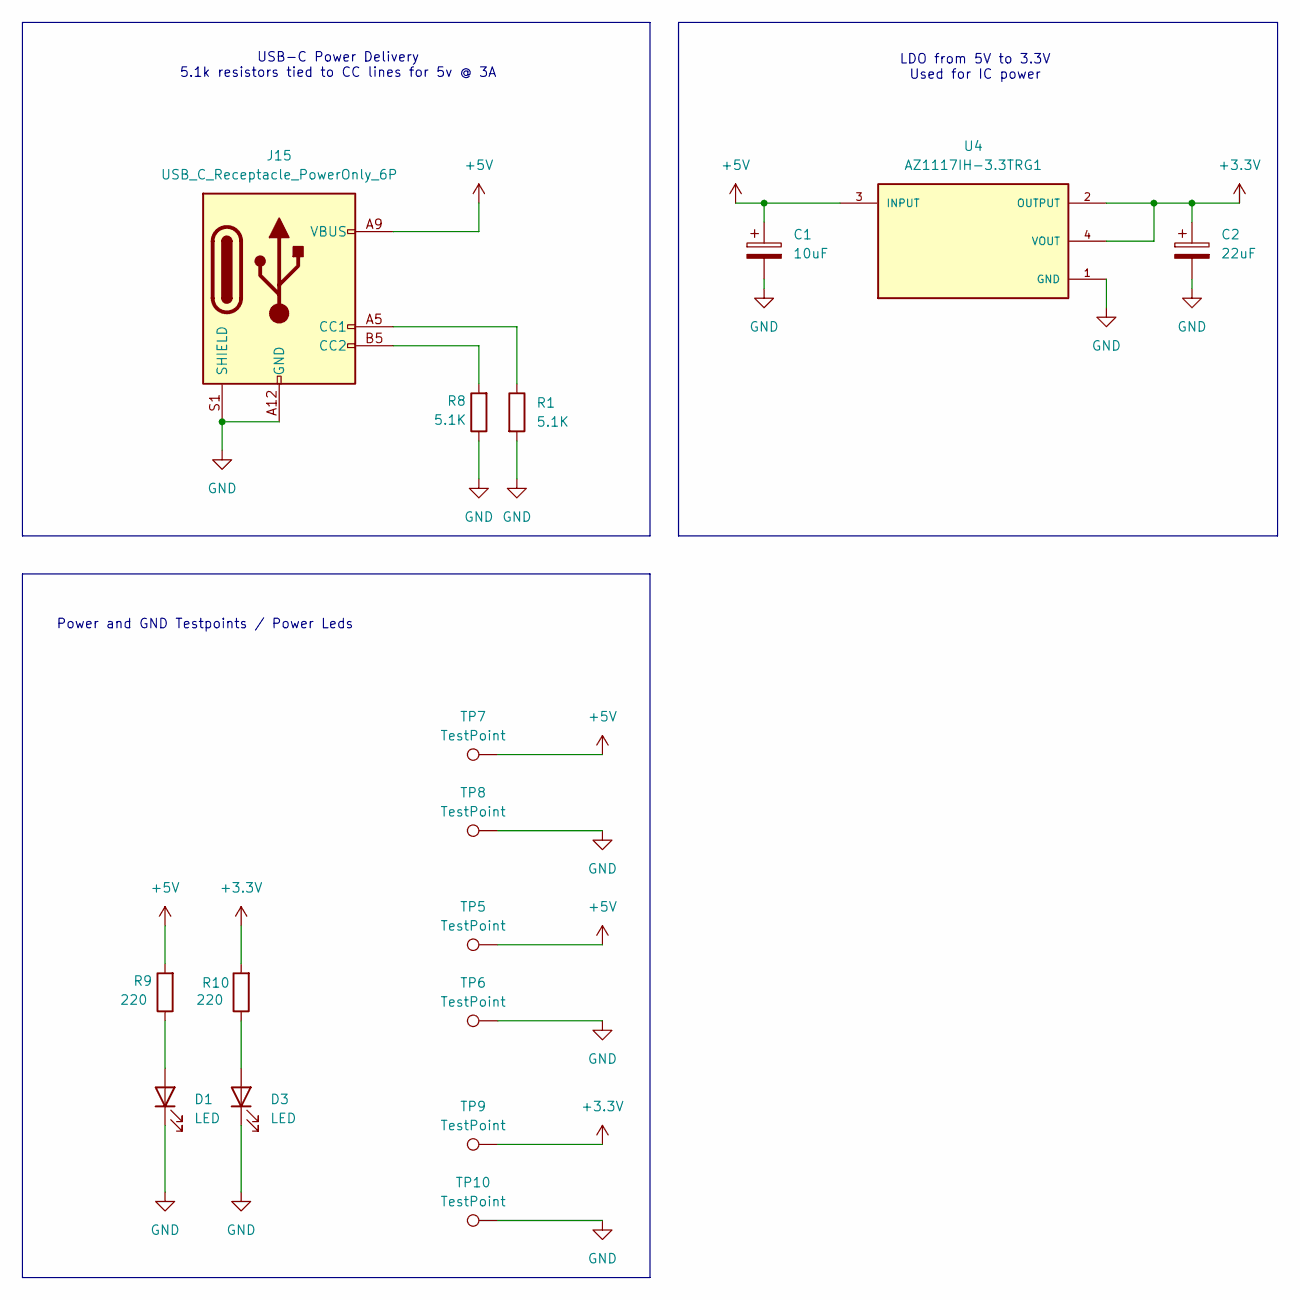
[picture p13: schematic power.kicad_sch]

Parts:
C1: 10uF; C_0603_1608Metric
C2: 22uF; C_0603_1608Metric
D1, D3: LED; LED_0603_1608Metric
J15: USB_C_Receptacle_PowerOnly_6P; USB_C_Receptacle_GCT_USB4125-xx-x-0190_6P_TopMnt_Horizontal
R1, R8: 5.1K; R_0603_1608Metric
R9, R10: 220; R_0603_1608Metric
TP5, TP6, TP7, TP8, TP9, TP10: TestPoint; TestPoint_Pad_3.0x3.0mm
U4: AZ1117IH-3.3TRG1; SOT230P700X185-4N; PARTREV 2-2

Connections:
+3.3V: C2.1, R10.2, TP9.1, U4.2 (OUTPUT), U4.4 (VOUT); also elsewhere on the board
+5V: C1.1, J15.A9 (VBUS), J15.B9 (VBUS), R9.2, TP5.1, TP7.1, U4.3 (INPUT); also elsewhere on the board
GND: C1.2, C2.2, D1.1 (K), D3.1 (K), J15.A12 (GND), J15.B12 (GND), J15.S1 (SHIELD), R1.2, R8.1, TP6.1, TP8.1, TP10.1, U4.1 (GND); also elsewhere on the board
unnamed: D1.2 (A), R9.1
unnamed: D3.2 (A), R10.1
unnamed: J15.A5 (CC1), R1.1
unnamed: J15.B5 (CC2), R8.2

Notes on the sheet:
USB-C Power Delivery 5.1k resistors tied to CC lines for 5v @ 3A
LDO from 5V to 3.3V Used for IC power
Power and GND Testpoints / Power Leds

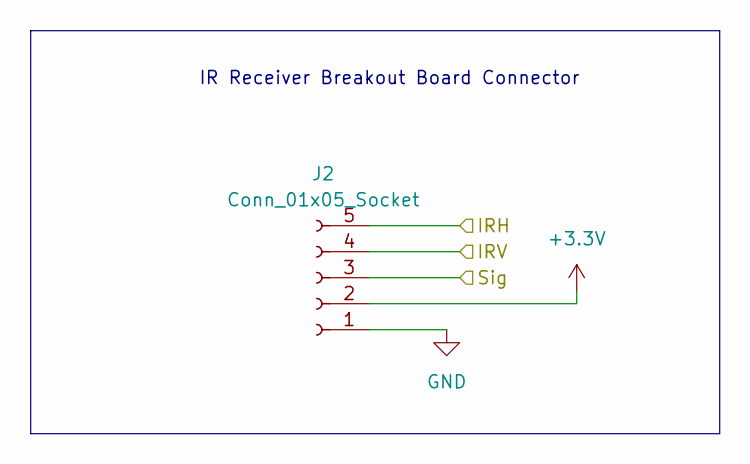
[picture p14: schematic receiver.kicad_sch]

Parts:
J2: Conn_01x05_Socket; PinHeader_1x05_P2.54mm_Vertical

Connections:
+3.3V: J2.2; also elsewhere on the board
/proton/IRH: J2.5; also elsewhere on the board
/proton/IRV: J2.4; also elsewhere on the board
/proton/Sig: J2.3; also elsewhere on the board
GND: J2.1; also elsewhere on the board

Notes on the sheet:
IR Receiver Breakout Board Connector

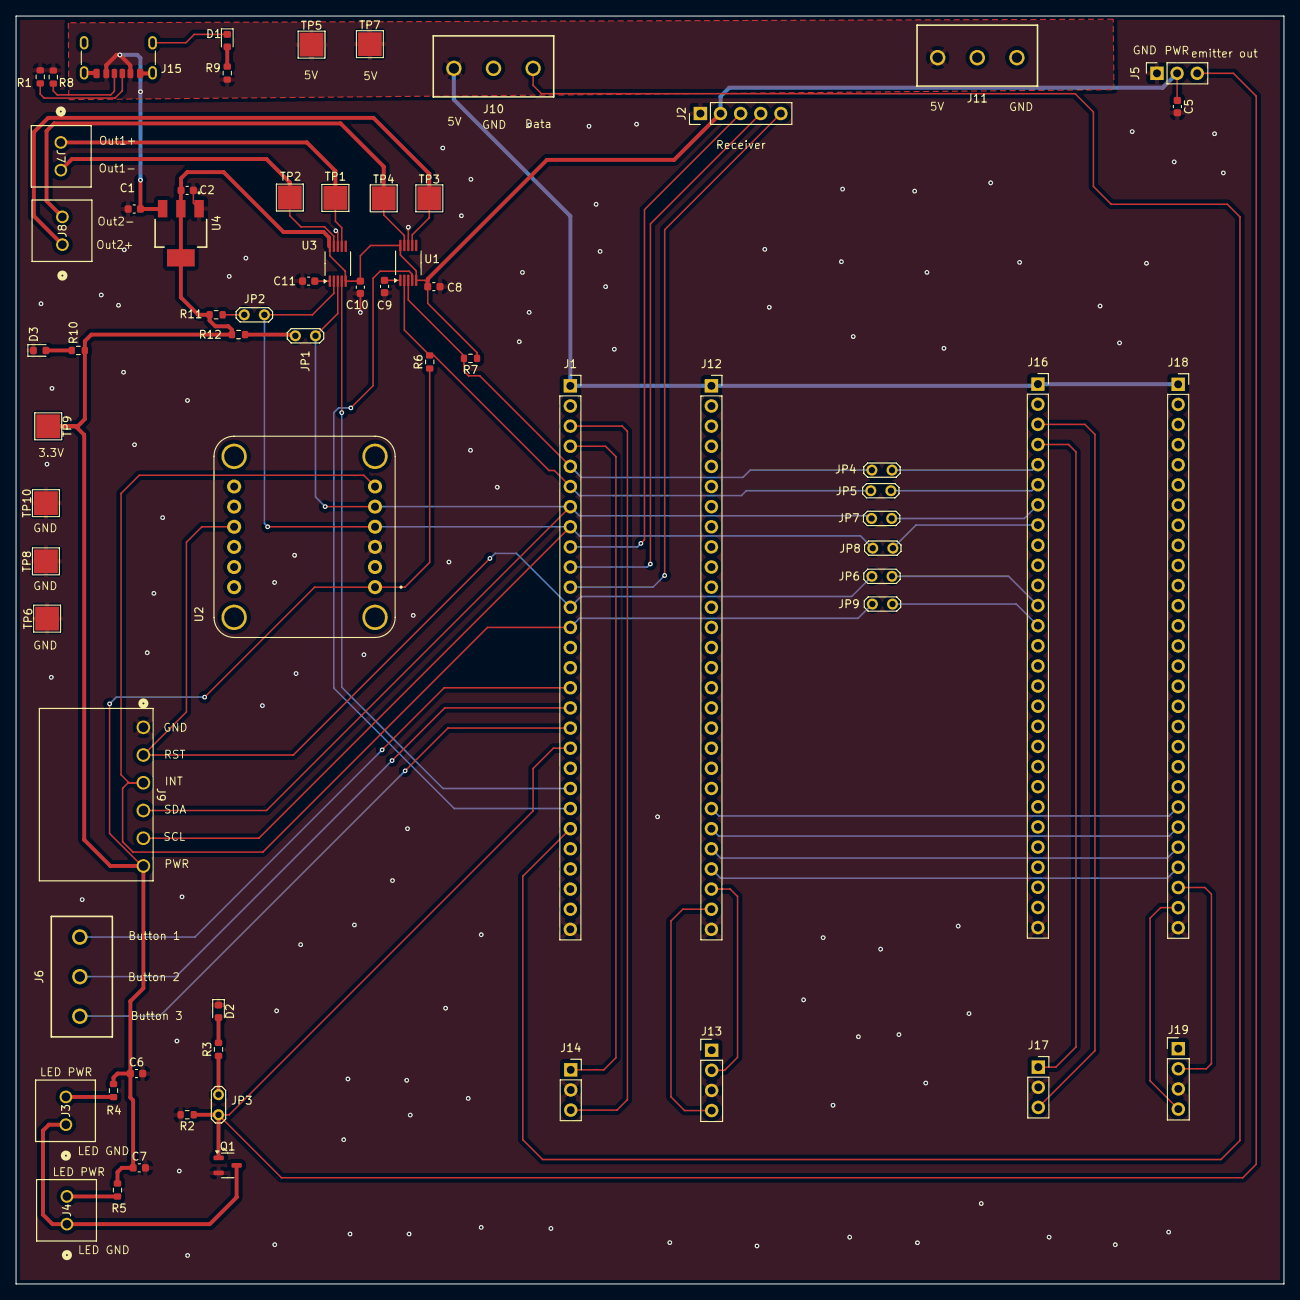
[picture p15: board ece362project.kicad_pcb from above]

Board: 2 copper layers, 160.0 x 160.0 mm, 67 parts (0 on the bottom side), 54 nets.

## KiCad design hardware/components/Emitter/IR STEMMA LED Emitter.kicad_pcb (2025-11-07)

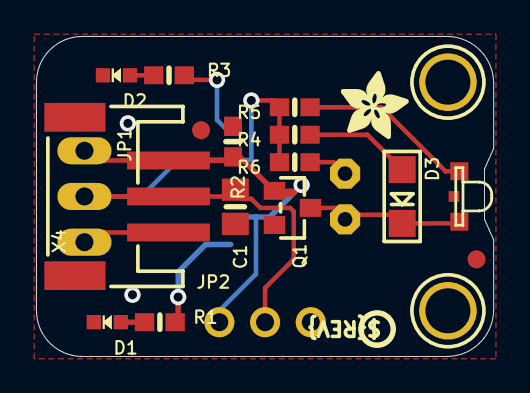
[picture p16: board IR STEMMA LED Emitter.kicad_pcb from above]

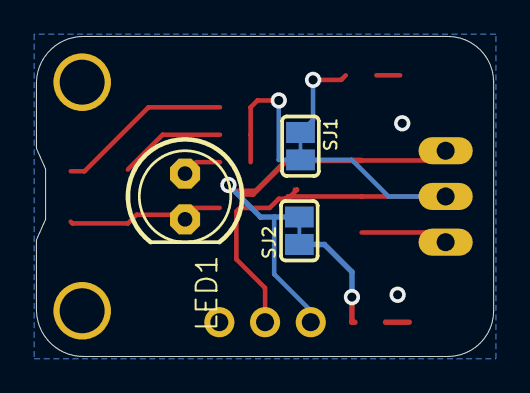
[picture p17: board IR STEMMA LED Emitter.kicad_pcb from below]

Board: 16 copper layers, 25.4 x 17.8 mm, 39 parts (14 on the bottom side), 11 nets.

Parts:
C1: 10uF; 0805-NO
D1: RED; CHIPLED_0603_NOOUTLINE
D2: GREEN; CHIPLED_0603_NOOUTLINE
D3: 1206 IR 940nm; CHIPLED_1206
D4: 1206 IR 940nm Side; LED_1206_SIDE
FID2, FID3: FIDUCIAL_1MM
JP1: 0.1" Header; 1X03_OVAL
JP2: 0.1" Header; 1X03_ROUND
LED1: 5mm; LED5MM
PLABEL0: PLABEL0
PLABEL00: PLABEL00
PLABEL1: PLABEL1
PLABEL2: PLABEL2
PLABEL3: PLABEL3
PLABEL4: PLABEL4
PLABEL5: PLABEL5
PLABEL6: PLABEL6
PLABEL7: PLABEL7
PLABEL8: PLABEL8
PLABEL9: PLABEL9
PLABEL10: PLABEL10
PLABEL11: PLABEL11
PLABEL13: PLABEL13
PLABEL14: PLABEL14
Q1: AO3406; SOT23-WIDE
R1, R2: 10K; 0603-NO
R3: 33K; 0603-NO
R4, R5, R6: 22; 0603-NO
SJ1, SJ2: SOLDERJUMPER_CLOSEDWIRE
U$1, U$8: MOUNTINGHOLE2.5; MOUNTINGHOLE_2.5_PLATED
U$5: PCBFEAT-REV-040
U$10: ADAFRUIT_3.5MM
X4: JST PH 3; JSTPH3

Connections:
GND: C1.2, D1.C, D2.C, JP1.3, JP2.3, Q1.2, R2.1, X4.1
unnamed: R3.2, SJ1.1
unnamed: D1.A, R1.1
unnamed: R1.2, SJ2.1
unnamed: D3.C, D4.C, LED1.K, Q1.3
unnamed: D3.A, R4.1
unnamed: D4.A, R5.1
unnamed: LED1.A, R6.1
unnamed: D2.A, R3.1
SIGNAL: JP1.1, JP2.1, Q1.1, R2.2, SJ2.2, X4.3
VIN: C1.1, JP1.2, JP2.2, R4.2, R5.2, R6.2, SJ1.2, X4.2

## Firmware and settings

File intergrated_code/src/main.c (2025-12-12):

#include <stdio.h>
#include <string.h>
#include <math.h>
#include <stdlib.h>
#include "pico/stdlib.h"
#include "pico/multicore.h"
#include "pico/util/queue.h"
#include "hardware/i2c.h"
#include "hardware/watchdog.h" // Still included for hardware header definitions, but functions are removed.
#include "pico/multicore_lockout.h"
// --- Drivers ---
#include "bno08x_driver.h"
#include "ei_bridge.h" 
#include "ir_emitter.h"
#include "irremote.h"
#include "drv2605.h"
#include "ws2812.h"
#include "controller.h"
#include "healthbar.h"

// ===========================================================================
// --- 1. SPELL CONFIGURATION ---
// ===========================================================================
// Define the machine learning labels and their corresponding integer IDs.
#define SPELL_LABEL_1             "aguamenti"
#define SPELL_ID_1                1
#define SPELL_LABEL_2             "stupefy"
#define SPELL_ID_2                2

// ===========================================================================
// --- 2. SENSITIVITY & TRIGGER TUNING ---
// ===========================================================================

// [CRITICAL] How many successful AI frames are needed to cast?
// The AI runs approx 4 times a second (every 250ms).
// 6 frames = ~1.5 seconds of holding the gesture.
// Increase this to make it harder/less sensitive. Decrease for instant casting.
#define FRAMES_TO_TRIGGER         6    

// How fast the "charge" decays if you stop doing the gesture (0-100 scale)
#define DECAY_RATE_IDLE           5    // Decay when no gesture is detected.
#define DECAY_RATE_WRONG_SPELL    10    // Faster decay when the wrong spell is detected.

// Internal Math (Do not edit)
#define MAX_SCORE                 100 // Full charge score
#define SCORE_INCREMENT           (MAX_SCORE / FRAMES_TO_TRIGGER) // Score gained per successful AI frame
#define SCORE_TRIGGER_LEVEL       (MAX_SCORE - 5) // Trigger when nearly full

// ===========================================================================
// --- 3. TIMING PARAMETERS (milliseconds) ---
// ===========================================================================

// Delay between "Spell Recognized" and "IR Packet Sent"
// (Gives time for sound effect buildup or animation wind-up)
#define CAST_PRE_DELAY_MS         600  

// How long you must wait AFTER firing before firing again
#define CAST_COOLDOWN_MS          1500  

// How long to ignore the AI after a successful trigger 
// (Prevents the wand from machine-gunning the same spell)
#define AI_IGNORE_WINDOW_MS       2500  

// Time to stay dead before respawning
#define RESPAWN_DELAY_MS          7000

// ===========================================================================
// --- 4. HARDWARE CONFIGURATION ---
// ===========================================================================
// Unique IDs for IR communication
#define MY_PLAYER_ID              2
#define OPPONENT_PLAYER_ID        1

// I2C pins for BNO08x (IMU) and DRV2605 (Haptic)
#define I2C_PORT                  i2c0
#define I2C_SDA_PIN               16
#define I2C_SCL_PIN               17
// IR pins
#define TX_PIN                    36 // Example, actual pin varies by board
#define RX_PIN                    15
// Debug/Manual Trigger Buttons
#define BTN_A_PIN                 21
#define BTN_B_PIN                 26

// Queue Buffer Size (Max pending spells to fire)
#define QUEUE_SIZE                4    
// How many IR packets to send per cast (Redundancy for reliable comms)
#define PACKET_REPEATS            3

// Sensor Settings
#define SAMPLING_FREQ_HZ          74 // BNO08x poll rate
#define SENSOR_POLL_US            (1000000 / SAMPLING_FREQ_HZ)
#define INFERENCE_INTERVAL_MS     250 // Edge Impulse inference rate
#define EI_YPR_IN_DEGREES         1 // Output yaw, pitch, roll in degrees

// Motion Gating: Minimum movement (m/s^2 deviation from gravity) required to run AI
// Prevents running AI when the wand is stationary.
#define MOTION_THRESHOLD          3.0f 

#ifndef M_PI
#define M_PI 3.14159265358979323846f
#endif

// ===========================================================================
// --- QUEUES & STRUCTS ---
// ===========================================================================
// Queue for passing AI results (spell decisions) from Core 1 to Core 0
static queue_t result_queue;
// Enum for haptic feedback commands
typedef enum { HAPTIC_NONE, HAPTIC_CAST, HAPTIC_HIT } haptic_cmd_t;
// Queue for passing haptic commands from Core 0 to Core 1
static queue_t haptic_queue;

// Circular buffer implementation for spells waiting to be transmitted (IR TX)
typedef struct {
    uint8_t buffer[QUEUE_SIZE];
    int head; // Index of the next spell to dequeue (send)
    int tail; // Index where the next spell will be enqueued
    int count; // Current number of spells in the queue
} SpellQueue;

static SpellQueue tx_queue = { .head = 0, .tail = 0, .count = 0 };

/**
 * @brief Adds a spell ID to the transmission queue.
 * @param spell_id The ID of the spell to enqueue.
 */
void enqueue_spell(uint8_t spell_id) {
    if (tx_queue.count >= QUEUE_SIZE) return; // Queue is full
    tx_queue.buffer[tx_queue.tail] = spell_id;
    tx_queue.tail = (tx_queue.tail + 1) % QUEUE_SIZE;
    tx_queue.count++;
    printf(">> Spell %d Queued (Firing in %d ms)...\n", spell_id, CAST_PRE_DELAY_MS);
}

/**
 * @brief Removes and returns the next spell ID from the transmission queue.
 * @return The spell ID, or 0 if the queue is empty.
 */
uint8_t dequeue_spell() {
    if (tx_queue.count == 0) return 0;
    uint8_t spell = tx_queue.buffer[tx_queue.head];
    tx_queue.head = (tx_queue.head + 1) % QUEUE_SIZE;
    tx_queue.count--;
    return spell;
}

// ===========================================================================
// --- CORE 1: SENSOR WORKER ---
// ===========================================================================
static bno08x_driver_t bno08x;
static drv2605_t haptic;

/**
 * @brief Core 1 main execution function. Handles sensors, haptics, and ML inference.
 */
void core1_entry() {
    // 1. I2C and Haptic Setup
    i2c_init(I2C_PORT, 400 * 1000);
    gpio_set_function(I2C_SDA_PIN, GPIO_FUNC_I2C);
    gpio_set_function(I2C_SCL_PIN, GPIO_FUNC_I2C);
    gpio_pull_up(I2C_SDA_PIN);
    gpio_pull_up(I2C_SCL_PIN);

    drv2605_init(&haptic, I2C_PORT, I2C_SDA_PIN, I2C_SCL_PIN);
    drv2605_set_mode(&haptic, DRV2605_MODE_INTTRIG);
    drv2605_select_library(&haptic, 1);

    // 2. BNO08x IMU Setup
    if (!bno08x_begin_i2c(&bno08x, I2C_PORT, BNO08x_I2CADDR_DEFAULT, -1)) {
        // IMU failed to initialize, halt Core 1
        while(1) { sleep_ms(100); } 
    }
    // Enable the required sensor reports for the ML model
    bno08x_enable_report(&bno08x, SH2_ARVR_STABILIZED_RV, SENSOR_POLL_US); // Orientation (for YPR)
    bno08x_enable_report(&bno08x, SH2_ACCELEROMETER, SENSOR_POLL_US); // Acceleration

    // 3. Edge Impulse Data Buffer Setup
    size_t frame_size = ei_bridge_get_input_frame_size();
    int axes = ei_bridge_get_axis_count();
    float *features = (float*)calloc(frame_size, sizeof(float));
    
    // Sensor data structures
    sh2_SensorValue_t val;
    sh2_Accelerometer_t acc = {0};
    struct { float y, p, r; } ypr = {0}; // Yaw, Pitch, Roll
    
    int samples = 0;
    uint64_t last_poll_time = 0;
    uint64_t last_inf_time = 0;
    // Index where the next sample should be written (end of the buffer)
    int move_idx = frame_size - axes;

    // 4. Main Sensor Loop
    while(true) {
        uint64_t now = to_us_since_boot(get_absolute_time());

        // Haptic feedback processing
        haptic_cmd_t h_cmd;
        if (queue_try_remove(&haptic_queue, &h_cmd)) {
            if (h_cmd == HAPTIC_CAST) drv2605_play_cast_feedback(&haptic);
            if (h_cmd == HAPTIC_HIT)  drv2605_play_hit_feedback(&haptic);
        }

        // Sensor Polling
        if (now - last_poll_time >= SENSOR_POLL_US) {
            last_poll_time = now;
            // Read all available sensor events
            while (bno08x_get_sensor_event(&bno08x, &val)) {
                if (val.sensorId == SH2_ARVR_STABILIZED_RV) {
                    // Convert Rotation Vector Quaternion to Yaw, Pitch, Roll
                    float qr = val.un.arvrStabilizedRV.real;
                    float qi = val.un.arvrStabilizedRV.i;
                    float qj = val.un.arvrStabilizedRV.j;
                    float qk = val.un.arvrStabilizedRV.k;
                    float sqr = qr*qr, sqi = qi*qi, sqj = qj*qj, sqk = qk*qk;
                    // Yaw calculation
                    ypr.y = atan2f(2.0f * (qi * qj + qk * qr), (sqi - sqj - sqk + sqr));
                    // Pitch calculation
                    ypr.p = asinf(-2.0f * (qi * qk - qj * qr) / (sqi + sqj + sqk + sqr));
                    // Roll calculation
                    ypr.r = atan2f(2.0f * (qj * qk + qi * qr), (-sqi - sqj + sqk + sqr));
                    if (EI_YPR_IN_DEGREES) {
                        float r2d = 180.0f / M_PI;
                        ypr.y *= r2d; ypr.p *= r2d; ypr.r *= r2d;
                    }
                } else if (val.sensorId == SH2_ACCELEROMETER) {
                    acc = val.un.accelerometer;
                }
            }
            // Shift the existing data one sample window back
            memmove(features, features + axes, move_idx * sizeof(float));
            // Add the new sensor data to the end of the buffer
            features[move_idx+0] = acc.x; features[move_idx+1] = acc.y; features[move_idx+2] = acc.z;
            features[move_idx+3] = ypr.r; features[move_idx+4] = ypr.p; features[move_idx+5] = ypr.y;
            samples++;
        }

        // Motion Gating and Inference Logic
        float mag = sqrtf(acc.x*acc.x + acc.y*acc.y + acc.z*acc.z);
        // Check if the acceleration magnitude is significantly different from gravity (9.8m/s^2)
        if (fabsf(mag - 9.8f) > MOTION_THRESHOLD) {
            // Check if the buffer is full (ready for inference)
            if (samples >= (frame_size/axes)) {
                uint64_t now_ms = now / 1000;
                // Check inference interval
                if ((now_ms - last_inf_time) >= INFERENCE_INTERVAL_MS) {
                    last_inf_time = now_ms;
                    // Run the trained ML model
                    spell_decision_t res = ei_bridge_run_inference(features, frame_size);
                    // Send result to Core 0
                    if (!queue_try_add(&result_queue, &res)) {}
                }
            }
        }
    }
}

// ===========================================================================
// --- CORE 0: GAME LOGIC ---
// ===========================================================================

/**
 * @brief Requests haptic feedback to be played by Core 1.
 * @param type The haptic command (HAPTIC_CAST or HAPTIC_HIT).
 */
void request_haptic(haptic_cmd_t type) {
    queue_try_add(&haptic_queue, &type);
}

/**
 * @brief Processes the effects when the player is hit by an opponent's spell.
 * @param spell_num The ID of the incoming spell.
 */
void process_hit_effects(uint8_t spell_num) {
    int anim_id = 0;
    int damage = 0;
    switch(spell_num) {
        case SPELL_ID_1: printf("Hit: Aguamenti!\n"); anim_id = 3; damage = 3; break;
        case SPELL_ID_2: printf("Hit: Stupefy!\n"); anim_id = 0; damage = 5; break;
        default: return;
    }
    hb_update(-damage); // Reduce health
    // Lock out Core 1 to safely update the shared WS2812 resource
    ws2812_clear();
    multicore_lockout_start(); 
    controller(anim_id, 16, 16); // Play a hit animation (e.g., on the health bar LEDs)
    multicore_lockout_end();
    hb_draw(); // Redraw the updated health bar
}

/**
 * @brief Clamps the spell score between 0 and MAX_SCORE.
 * @param score The current score.
 * @return The clamped score.
 */
int clamp_score(int score) {
    if (score > MAX_SCORE) return MAX_SCORE;
    if (score < 0) return 0;
    return score;
}

int main() {
    // Initialisation
    stdio_init_all();
    sleep_ms(2000);
    printf("=== WAND DUEL: PARAMETERIZED ===\n");
    printf("Frames to Trigger: %d (Score/Frame: %d)\n", FRAMES_TO_TRIGGER, SCORE_INCREMENT);

    // Watchdog update has been removed to prevent random resets.
    // watchdog_enable(2000, 1);

    // Inter-core communication queues
    queue_init(&result_queue, sizeof(spell_decision_t), 4);
    queue_init(&haptic_queue, sizeof(haptic_cmd_t), 4);

    // Driver initialisation
    ir_emitter_init(TX_PIN);
    ir_receiver_init(RX_PIN);
    ws2812_init(); // Health bar LEDs
    hb_init(16, 16); // Initialise health bar (max health, current health)
    hb_draw(); // Draw initial health bar

    // Button setup
    gpio_init(BTN_A_PIN); gpio_set_dir(BTN_A_PIN, GPIO_IN); gpio_pull_down(BTN_A_PIN);
    gpio_init(BTN_B_PIN); gpio_set_dir(BTN_B_PIN, GPIO_IN); gpio_pull_down(BTN_B_PIN);

    // Launch Core 1
    multicore_launch_core1(core1_entry);

    // Game State Variables
    ir_decoded_data_t rx_data;
    uint32_t death_time = 0;
    bool is_dead = false;
    int score_s1 = 0, score_s2 = 0; // Spell charge scores
    
    uint32_t last_trigger_time = 0; // Last time a spell was triggered/cast
    uint32_t next_cast_allowed_time = 0; // Earliest time a spell can physically fire
    spell_decision_t ai_result;

    // Main Game Loop
    while (true) {
        // Watchdog update has been removed.
        // watchdog_update();

        uint32_t now = to_ms_since_boot(get_absolute_time());

        // 1. AI Processing (Reading results from Core 1)
        if (queue_try_remove(&result_queue, &ai_result)) {
            // If inside the "Ignore Window" after a cast, reset score and ignore the AI result
            if (now - last_trigger_time < AI_IGNORE_WINDOW_MS) {
                score_s1 = 0; score_s2 = 0;
            } else {
                if (ai_result.detected) {
                    // Successful detection
                    if (strcmp(ai_result.label, SPELL_LABEL_1) == 0) {
                        score_s1 += SCORE_INCREMENT; 
                        score_s2 -= DECAY_RATE_WRONG_SPELL; // Decay other spell's score
                    } else if (strcmp(ai_result.label, SPELL_LABEL_2) == 0) {
                        score_s2 += SCORE_INCREMENT; 
                        score_s1 -= DECAY_RATE_WRONG_SPELL; // Decay other spell's score
                    }
                } else {
                    // No spell detected (idle)
                    score_s1 -= DECAY_RATE_IDLE; 
                    score_s2 -= DECAY_RATE_IDLE;
                }
                // Clamp the scores
                score_s1 = clamp_score(score_s1); score_s2 = clamp_score(score_s2);

                // Trigger Logic
                if (score_s1 >= SCORE_TRIGGER_LEVEL || score_s2 >= SCORE_TRIGGER_LEVEL) {
                    // Determine which spell to fire
                    uint8_t spell = (score_s1 >= SCORE_TRIGGER_LEVEL) ? SPELL_ID_1 : SPELL_ID_2;
                    
                    // Enqueue the spell for a delayed fire
                    enqueue_spell(spell);
                    request_haptic(HAPTIC_CAST); 

                    // Calculate the earliest time the IR packet can be sent (pre-delay)
                    uint32_t earliest_fire_time = now + CAST_PRE_DELAY_MS;
                    // Ensure the pre-delay doesn't override an existing cooldown
                    if (next_cast_allowed_time < earliest_fire_time) {
                        next_cast_allowed_time = earliest_fire_time;
                    }

                    // Reset Score & Cooldown window
                    score_s1 = 0; score_s2 = 0;
                    last_trigger_time = now;
                }
            }
        }

        // 2. Respawn Logic
        if (is_dead) {
            if (now - death_time > RESPAWN_DELAY_MS) {
                is_dead = false;
                hb_reset(); // Restore full health
                hb_draw();
                printf(">>> Respawned\n");
            }
        } 
        // 3. Manual Buttons (Test/Alternative Input)
        else {
            uint8_t btn_spell = 0;
            if (gpio_get(BTN_A_PIN)) btn_spell = SPELL_ID_1;
            if (gpio_get(BTN_B_PIN)) btn_spell = SPELL_ID_2;
            
            if (btn_spell > 0) {
                // Manual triggers skip the AI score logic, but still respect pre-delay
                enqueue_spell(btn_spell);
                request_haptic(HAPTIC_CAST);
                
                uint32_t fire_time = now + CAST_PRE_DELAY_MS;
                if (next_cast_allowed_time < fire_time) {
                    next_cast_allowed_time = fire_time;
                }
                // Simple debounce/prevent spam
                sleep_ms(200);
            }
        }

        // 4. Firing Logic (IR Transmission)
        if (!is_dead && tx_queue.count > 0) {
            if (now >= next_cast_allowed_time) {
                uint8_t spell_to_cast = dequeue_spell();
                if (spell_to_cast > 0) {
                    // Transmit the IR packet
                    ir_emitter_start(MY_PLAYER_ID, spell_to_cast, PACKET_REPEATS);
                    printf(">>> FIRING SPELL %d (t=%lu)\n", spell_to_cast, now);
                    
                    // Apply Cooldown AFTER firing
                    next_cast_allowed_time = now + CAST_COOLDOWN_MS;
                }
            }
        }

        // 5. Receiver Logic (IR Reception)
        if (ir_receiver_decode(&rx_data)) {
            // Check if the IR packet is for this player (address = OPPONENT_PLAYER_ID)
            if (rx_data.protocol == IR_PROTOCOL_NEC && rx_data.address == OPPONENT_PLAYER_ID) {
                request_haptic(HAPTIC_HIT);
                process_hit_effects(rx_data.command);
                // Check for death condition
                if (hb_current() <= 0) {
                    is_dead = true;
                    death_time = now;
                    // Play a death animation
                    loser_screen(16, 16);
                }
            }
        }

        // Update the IR transmitter state machine
        ir_emitter_update();
        // Sleep briefly to save power and yield to other processes
        sleep_ms(1);
    }
}

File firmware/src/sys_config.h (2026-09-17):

#ifndef SYS_CONFIG_H
#define SYS_CONFIG_H

#include "pico/stdlib.h"

// ==========================================
// --- PLAYER IDENTITY & DEBUG ---
// ==========================================
// Change this to 2 for the second wand!
#define PLAYER_ID           1   

// Set to 1 to allow shooting yourself (for testing/single wand)
// Set to 0 for actual duel (ignore your own IR signals)
#define ALLOW_SELF_HIT      1   

// ==========================================
// --- HARDWARE PINOUT ---
// ==========================================

// I2C0: IMU (BNO08x) & Haptics (Shared Bus)
#define I2C_IMU_PORT        i2c0
#define PIN_IMU_SDA         4
#define PIN_IMU_SCL         5

#define I2C_HAPTIC_PORT     i2c0
#define PIN_HAPTIC_SDA      4
#define PIN_HAPTIC_SCL      5

// LED Matrix (WS2812)
#define PIN_LED             20  
#define NUM_LEDS            256
#define LED_DMA_CHANNEL     0
#define MATRIX_WIDTH        16
#define MATRIX_HEIGHT       16

// IR Comms
#define PIN_IR_TX           16
#define PIN_IR_RX           6

// Buttons
#define PIN_BTN_SHIELD      21

// ==========================================
// --- GAMEPLAY & AI TUNING ---
// ==========================================

// 1. CONFIDENCE
#define AI_CONFIDENCE_THRESHOLD  0.9f  

// 2. ANOMALY THRESHOLDS
#define ANOMALY_THRESH_AGUAMENTI  2.3f  
#define ANOMALY_THRESH_STUPEFY    2.6f  

// 3. TRIGGER LOGIC ("The Bucket")
#define SPELL_TRIGGER_TARGET     7      
#define SPELL_DECAY_RATE         2      

// 4. SHIELD MECHANICS
#define SHIELD_COOLDOWN_MS       10000   // 10 Seconds cooldown

// Timings
#define SENSOR_POLL_RATE_HZ      74     
#define SENSOR_POLL_US           (1000000 / SENSOR_POLL_RATE_HZ)
#define POST_CAST_LOCKOUT_MS     2000   
#define AI_CHECK_INTERVAL_MS     100    

// ==========================================
// --- INTER-CORE COMMUNICATION ---
// ==========================================
typedef union {
    struct {
        uint8_t reserved;
        uint8_t anomaly;    // Scaled 0-100 
        uint8_t confidence; // Scaled 0-100
        uint8_t spell_id;   // 0-255
    } parts;
    uint32_t packed;
} ai_result_t;

// Spell IDs
#define SPELL_LOGIC_NONE        0
#define SPELL_LOGIC_AGUAMENTI   1
#define SPELL_LOGIC_STUPEFY     2

#endif // SYS_CONFIG_H

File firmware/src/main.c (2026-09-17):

/**
 * @file main.c
 * @brief Dual-Core Wand Duel - Self-Hit Toggle Added
 */

#include <stdio.h>
#include <string.h>
#include <math.h>
#include <stdlib.h>
#include "pico/stdlib.h"
#include "pico/multicore.h"
#include "pico/util/queue.h"
#include "hardware/i2c.h"

// --- Configuration ---
#include "sys_config.h"

// --- Drivers ---
#include "bno08x_driver.h"
#include "ei_bridge.h" 
#include "ir_emitter.h"
#include "irremote.h"
#include "drv2605.h"
#include "ws2812.h"
#include "controller.h" 
#include "healthbar.h"  

// ===========================================================================
// --- AI DATA BUFFERS ---
// ===========================================================================
#define WINDOW_MS 1650
#define SAMPLES_PER_WINDOW ((WINDOW_MS * SENSOR_POLL_RATE_HZ) / 1000)
#define AXES_COUNT 6 
#define EI_FEATURE_SIZE (SAMPLES_PER_WINDOW * AXES_COUNT)
#define RING_BUFFER_SIZE (3 * SENSOR_POLL_RATE_HZ * AXES_COUNT)

static float sensor_ring_buffer[RING_BUFFER_SIZE];
static volatile int rb_head = 0; 
static float exchange_buffer[EI_FEATURE_SIZE];
static volatile bool ai_is_busy = false;

// Driver Instances
static bno08x_driver_t bno08x;
static drv2605_t haptic;

// Core 1 Stack
static uint32_t core1_stack[4096] __attribute__((aligned(8)));

// ===========================================================================
// --- DATA HELPERS ---
// ===========================================================================
void rb_push(float x, float y, float z, float r, float p, float yaw) {
    sensor_ring_buffer[rb_head++] = x; sensor_ring_buffer[rb_head++] = y;
    sensor_ring_buffer[rb_head++] = z; sensor_ring_buffer[rb_head++] = r;
    sensor_ring_buffer[rb_head++] = p; sensor_ring_buffer[rb_head++] = yaw;
    if (rb_head >= RING_BUFFER_SIZE) rb_head = 0;
}

void rb_unroll_to_exchange() {
    int count = EI_FEATURE_SIZE;
    int start_idx = rb_head - count;
    if (start_idx < 0) {
        start_idx += RING_BUFFER_SIZE;
        int part_a = RING_BUFFER_SIZE - start_idx;
        memcpy(exchange_buffer, &sensor_ring_buffer[start_idx], part_a * sizeof(float));
        memcpy(&exchange_buffer[part_a], &sensor_ring_buffer[0], (count - part_a) * sizeof(float));
    } else {
        memcpy(exchange_buffer, &sensor_ring_buffer[start_idx], count * sizeof(float));
    }
}

// ===========================================================================
// --- CORE 1: THE BRAIN (AI) ---
// ===========================================================================
void core1_entry() {
    while (true) {
        uint32_t cmd = multicore_fifo_pop_blocking();
        if (cmd == 1) {
            spell_decision_t res = ei_bridge_run_inference(exchange_buffer, EI_FEATURE_SIZE);
            
            ai_result_t result;
            result.parts.spell_id = SPELL_LOGIC_NONE;
            
            if (strcmp(res.label, "aguamenti") == 0) result.parts.spell_id = SPELL_LOGIC_AGUAMENTI;
            else if (strcmp(res.label, "stupefy") == 0) result.parts.spell_id = SPELL_LOGIC_STUPEFY;

            result.parts.confidence = (uint8_t)(res.confidence * 100);
            
            float anom_clamped = (res.anomaly_score > 10.0f) ? 10.0f : res.anomaly_score;
            result.parts.anomaly = (uint8_t)(anom_clamped * 10); 

            multicore_fifo_push_blocking(result.packed);
        }
    }
}

// ===========================================================================
// --- CORE 0: THE BODY (Game Loop) ---
// ===========================================================================
int main() {
    stdio_init_all();
    sleep_ms(2000); 
    printf("=== WAND SYSTEM BOOT (ID: %d) ===\n", PLAYER_ID);

    // --- 1. Init Hardware ---
    i2c_init(I2C_IMU_PORT, 400 * 1000);
    gpio_set_function(PIN_IMU_SDA, GPIO_FUNC_I2C);
    gpio_set_function(PIN_IMU_SCL, GPIO_FUNC_I2C);
    gpio_pull_up(PIN_IMU_SDA);
    gpio_pull_up(PIN_IMU_SCL);

    // Haptics share I2C0
    
    if (drv2605_init(&haptic, I2C_HAPTIC_PORT, PIN_HAPTIC_SDA, PIN_HAPTIC_SCL)) {
        drv2605_set_mode(&haptic, DRV2605_MODE_INTTRIG);
        drv2605_select_library(&haptic, 1);
    }

    ws2812_init(); 
    ws2812_clear();
    hb_init(MATRIX_WIDTH, MATRIX_HEIGHT);
    hb_draw(); 

    // Buttons (Active High)
    gpio_init(PIN_BTN_SHIELD);
    gpio_set_dir(PIN_BTN_SHIELD, GPIO_IN);
    gpio_disable_pulls(PIN_BTN_SHIELD); 

    if (!bno08x_begin_i2c(&bno08x, I2C_IMU_PORT, BNO08x_I2CADDR_DEFAULT, -1)) {
        printf("IMU FAIL!\n");
        ws2812_fill(50, 0, 0); ws2812_update();
        while(1) { sleep_ms(100); } 
    }
    bno08x_enable_report(&bno08x, SH2_ARVR_STABILIZED_RV, SENSOR_POLL_US);
    bno08x_enable_report(&bno08x, SH2_ACCELEROMETER, SENSOR_POLL_US);

    ir_emitter_init(PIN_IR_TX); 
    ir_receiver_init(PIN_IR_RX);

    multicore_launch_core1_with_stack(core1_entry, core1_stack, sizeof(core1_stack));

    // --- Game State ---
    uint64_t last_poll_time = 0;
    uint64_t last_ai_check = 0;
    uint64_t next_valid_cast_time = 0; 
    uint64_t shield_cooldown_end = 0;

    uint32_t candidate_spell = SPELL_LOGIC_NONE;
    int      spell_score = 0;

    sh2_SensorValue_t val;
    sh2_Accelerometer_t acc = {0};
    struct { float y, p, r; } ypr = {0};

    printf("=== READY ===\n");

    while (true) {
        uint64_t now_us = to_us_since_boot(get_absolute_time());
        uint64_t now_ms = now_us / 1000;

        // ----------------------------------------
        // 0. SHIELD BUTTON LOGIC
        // ----------------------------------------
        if (gpio_get(PIN_BTN_SHIELD)) {
            if (now_ms > shield_cooldown_end) {
                printf(">>> SHIELD ACTIVE! <<<\n");
                
                controller(0, MATRIX_WIDTH, MATRIX_HEIGHT);
                
                ws2812_clear();
                hb_draw();
                
                ir_decoded_data_t trash;
                while(ir_receiver_decode(&trash)) {
                    ir_receiver_resume();
                }

                shield_cooldown_end = now_ms + SHIELD_COOLDOWN_MS;
                printf(">>> Shield Down. Cooldown active.\n");
            } 
        }
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

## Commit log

2025-10-26 added files to imu
2025-10-31 added new files for imu
2025-10-31 somewhat works (IMU)
2025-11-06 finished imu code basically
2025-11-11 copied moved files back into original folders
    Added back the files moved into IR folder (receiver lib, .c/.h files for emitter) back into their respective IR_Receiver and IR_Transmitter folders just in case we want to test separately in the futu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
2025-11-11 fixed a dependency issue
    [ir_emitter.c, main.c]
2025-11-11 using non-blocking dma
2025-11-11 "colors working for LED"
2025-11-11 deleted unnecessary prints/comments
2025-11-13 worked on dma
2025-11-14 integraed LED
2025-11-16 LED Matrix works without color
2025-11-16 led matrix done
2025-11-17 button integration
2025-11-17 button works
2025-11-20 led matrix
2026-09-17 Update latest working code: multicore, shield button, and self-hit toggle
2026-09-17 Reorganize project for portfolio, clean build artifacts, and add documentation
    [1751248.stp, 73099-0.step, AZ1117IH-3.3TRG1.step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]
